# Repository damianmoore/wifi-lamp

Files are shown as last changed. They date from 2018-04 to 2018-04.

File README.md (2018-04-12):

# WiFi Lamp

A simple wifi-enabled lamp control board based on the ESP8266. It is intended
primarily to help retrofit existing LED lamps, giving them switching and dimming
functionality through a web browser or home automation system.

The project is based around the ESP8266-01 module as it is widely available,
small, very cheap, easily programmable, and directly connects to your existing
wifi network.

The included electronics files (schematic and PCB layout) are designed in KiCad.

An RS-232 USB-to-serial convertor is required for programming. If you use this
adaptor to power the device while programming, it must output 3.3V (not higher).

## Specifications

 * Input voltage: **3.3 – 15V**
 * LED PWM dimmer frequency: **1000 Hz**

## Components (BOM)

 * ESP8266-01 module
 * AMS1117 3.3V voltage regulator, SOT-223 package
 * BCP53 transistor, SOT-223 package
 * 2 × SMD SPST switches, ~6mm wide × ~3mm deep
 * Row of 4 header pins

## Renderings

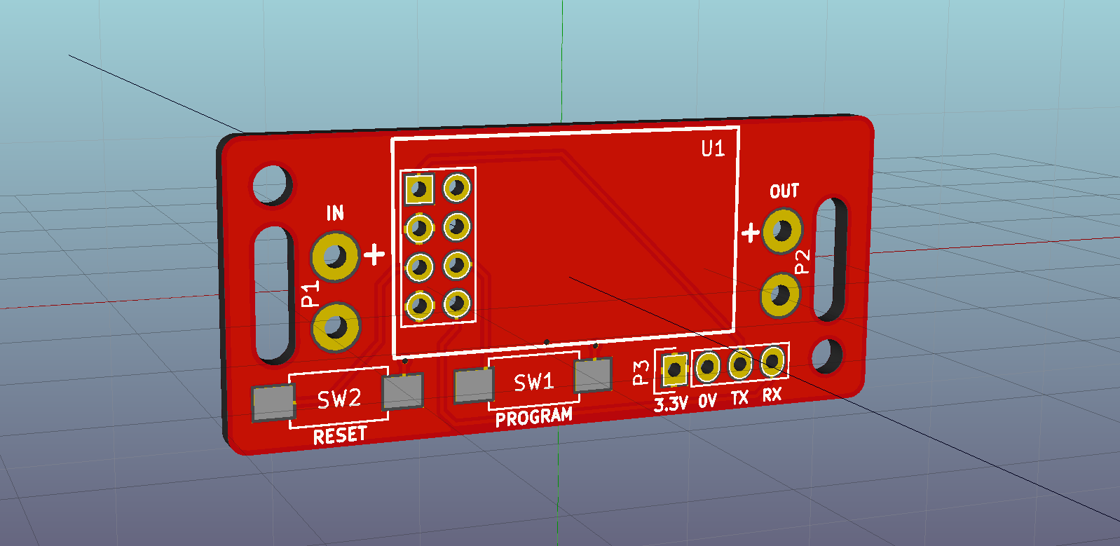
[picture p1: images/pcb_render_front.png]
PCB rendering (front)


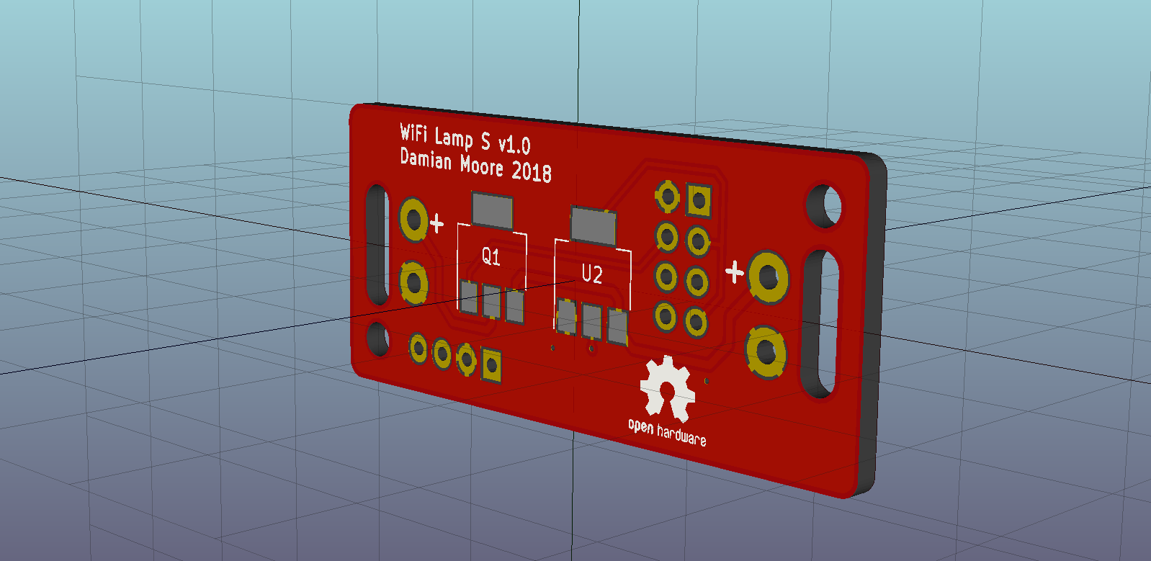
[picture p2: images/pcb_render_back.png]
PCB rendering (Back)


## Schematic

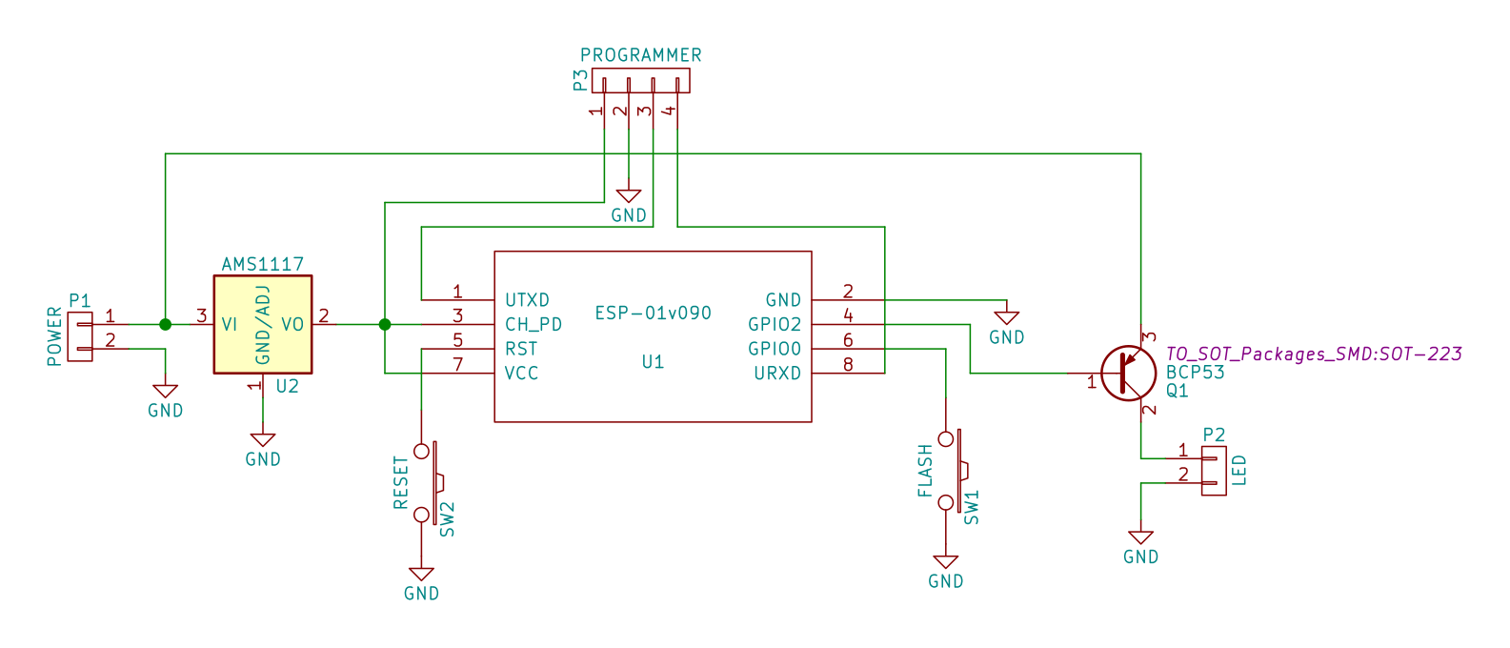
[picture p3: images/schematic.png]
Schematic


## Overview of the layers used for PCB production

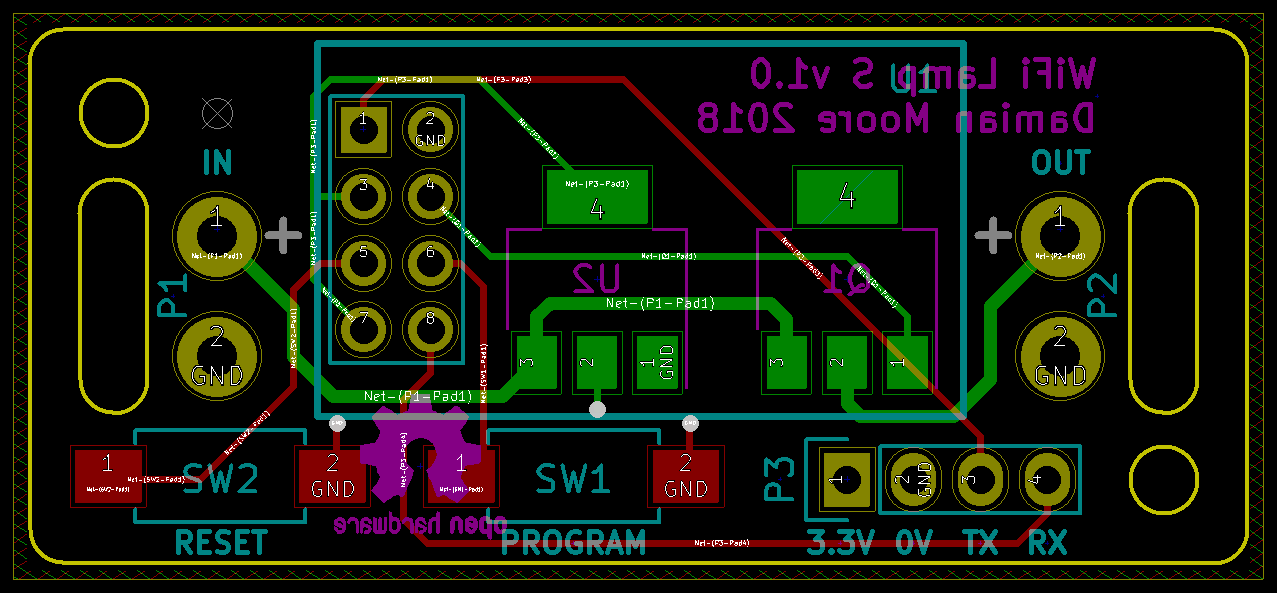
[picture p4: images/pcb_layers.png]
PCB layers


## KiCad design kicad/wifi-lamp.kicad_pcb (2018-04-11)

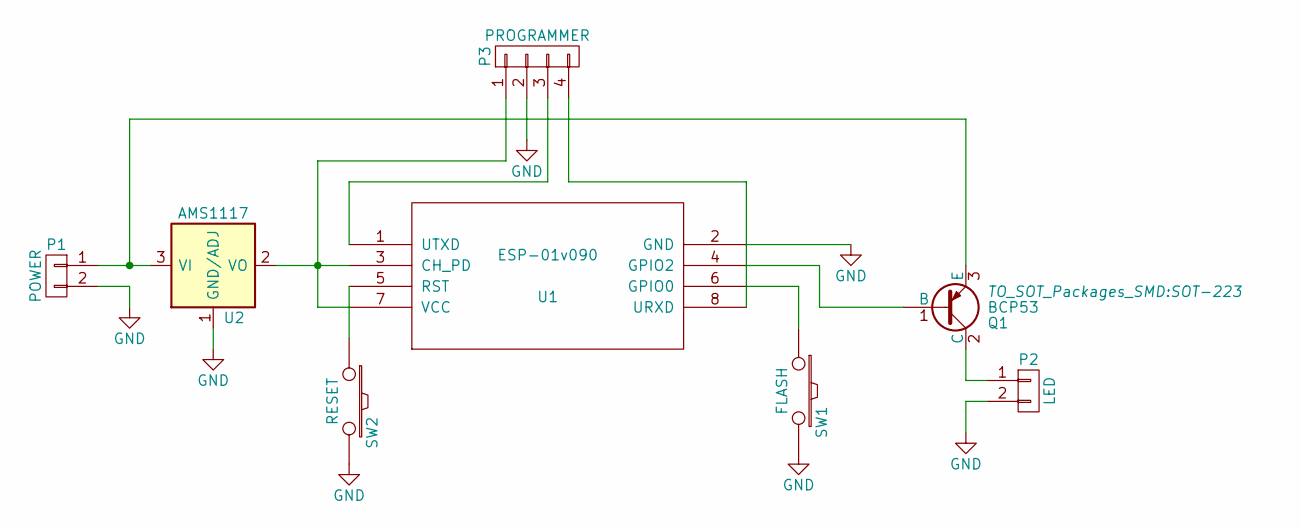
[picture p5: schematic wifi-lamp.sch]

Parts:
P1: POWER; WireConnection_1.50mmDrill
P2: LED; WireConnection_1.50mmDrill
P3: PROGRAMMER; Pin_Header_Straight_1x04
Q1: BCP53; SOT-223
SW1: FLASH; SW_SPST_REED_CT05-XXXX-G1
SW2: RESET; SW_SPST_REED_CT05-XXXX-G1
U1: ESP-01v090; ESP-01
U2: AMS1117; SOT-223

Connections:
GND: P1.2, P2.2, P3.2, SW1.2, SW2.2, U1.2 (GND), U2.1 (GND/ADJ)
unnamed: P1.1, Q1.3 (E), U2.3 (VI)
unnamed: P2.1, Q1.2 (C)
unnamed: P3.1, U1.3 (CH_PD), U1.7 (VCC), U2.2 (VO), U2.4 (VO)
unnamed: P3.3, U1.1 (UTXD)
unnamed: P3.4, U1.8 (URXD)
unnamed: Q1.1 (B), U1.4 (GPIO2)
unnamed: SW1.1, U1.6 (GPIO0)
unnamed: SW2.1, U1.5 (RST)

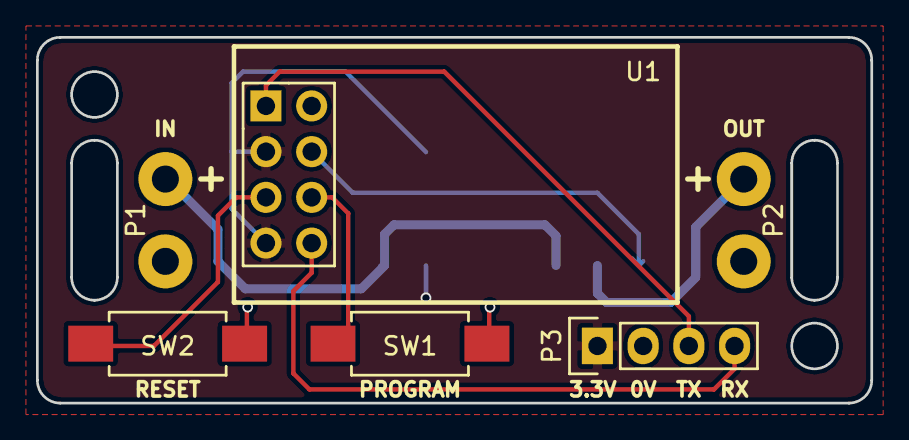
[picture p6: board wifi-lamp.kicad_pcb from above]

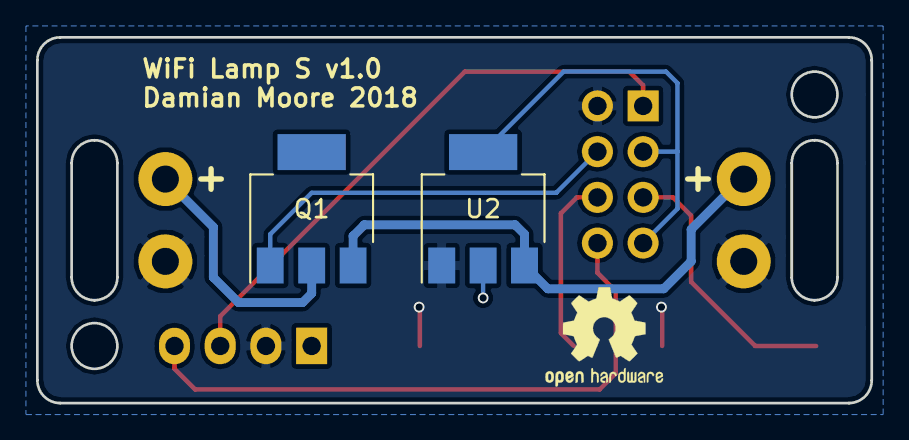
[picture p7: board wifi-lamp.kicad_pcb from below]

Board: 2 copper layers, 46.4 x 20.3 mm, 8 parts (2 on the bottom side), 9 nets.

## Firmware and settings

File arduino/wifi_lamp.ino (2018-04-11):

#include <ESP8266WiFi.h>          // ESP8266 Core WiFi Library

#include <DNSServer.h>            // Local DNS Server used for redirecting all requests to the configuration portal
#include <ESP8266WebServer.h>     // Local WebServer used to serve the configuration portal
#include <WiFiManager.h>          // https://github.com/tzapu/WiFiManager WiFi Configuration Magic

#include <ESP8266mDNS.h>


MDNSResponder mdns;

ESP8266WebServer server(80);

const int output = 2;
long brightness = 1023;


void handleRoot() {
  char temp[1000];
  int sec = millis() / 1000;
  int min = sec / 60;
  int hr = min / 60;
  float bFloat = float(brightness) / 1023;
  int b1 = (int)bFloat;
  int b2 = (int)((bFloat - b1) * 1000);

  snprintf (temp, 1000,

"<html>\
  <head>\
    <meta http-equiv=\"content-type\" content=\"text/html; charset=utf-8\">\
    <meta name=\"viewport\" content=\"width=device-width, initial-scale=1.0\">\
    <title>Wi-Fi Lamp</title>\
    <link href=\"https://cdn.rawgit.com/damianmoore/wifi-lamp/47a3120/style.css\" rel=\"stylesheet\" type=\"text/css\" \\>\
    <!--link href=\"http://localhost:8000/style.css\" rel=\"stylesheet\" type=\"text/css\" \\-->\
  </head>\
  <body>\
    <div id=\"app\"></div>\
    <script type=\"text/javascript\">\
      var configVars = {\
        brightnessRaw: %02d,\
        brightness: '%d.%d',\
        uptime: '%02d:%02d:%02d'\
      };\
    </script>\
    <script src=\"https://cdn.jsdelivr.net/react/0.13.3/JSXTransformer.js\" type=\"text/javascript\"></script>\
    <script src=\"https://cdn.jsdelivr.net/react/0.13.3/react.min.js\" type=\"text/javascript\"></script>\
    <script src=\"https://cdn.rawgit.com/damianmoore/wifi-lamp/187938e/script.js\" type=\"text/jsx\"></script>\
    <!--script src=\"http://localhost:8000/script.js\" type=\"text/jsx\"></script-->\
  </body>\
</html>",

    brightness, b1, b2, hr, min % 60, sec % 60
  );
  server.send(200, "text/html", temp);
}


void handleApi() {
  Serial.println("handleApi");
  String val = server.arg("val");
  Serial.println(val);
  char byte_buffer[val.length()+1];
  val.toCharArray(byte_buffer, val.length()+1);

  brightness = (atof(byte_buffer) * 1024) - 1;
  if (brightness < 0) {
    brightness = 0;
  }
  else if (brightness > 1023) {
    brightness = 1023;
  }

  analogWrite(output, 1023 - brightness);
  server.send(200, "text/plain", "OK");
}


void handleNotFound() {
  String message = "File Not Found\n\n";
  message += "URI: ";
  message += server.uri();
  message += "\nMethod: ";
  message += (server.method() == HTTP_GET) ? "GET" : "POST";
  message += "\nArguments: ";
  message += server.args();
  message += "\n";

  for (uint8_t i = 0; i < server.args(); i++) {
    message += " " + server.argName (i) + ": " + server.arg (i) + "\n";
  }

  server.send(404, "text/plain", message);
}


void setup (void) {
  pinMode(output, OUTPUT);
  analogWrite(output, 1023 - brightness);
  Serial.begin(115200);
  Serial.println("Starting...");
  WiFiManager wifiManager;
  wifiManager.autoConnect();

  server.on("/", handleRoot);
  server.on("/api/", handleApi);
  server.onNotFound (handleNotFound);
  server.begin();
  Serial.println("HTTP server started");
}


void loop (void) {
  mdns.update();
  server.handleClient();
}

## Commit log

2018-02-10 Arduino code
2018-04-11 Tidied up Arduino code
2018-04-11 Added KiCad files for first version of the PCB that's being made
    [wifi-lamp.kicad_pcb, wifi-lamp.sch]
